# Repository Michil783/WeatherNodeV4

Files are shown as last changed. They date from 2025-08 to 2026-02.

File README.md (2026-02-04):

# WeatherNodeV4

WeatherNode is a small HW device based on ESP8266 to capture actual weather conditions as temperature, pressure and humidity.
The data is send via Wifi to a MQTT broker.
The back office SW is stored in

https://github.com/Michil783/ClimateHist

The applications could run on a Raspberry Pi together with the MQTT broker.

For displaying the data I created a web page using the Astro framework based on an other github project.
More details could be found here: 

https://github.com/Michil783/weather-forecast

## Hardware

The hardware schema is done in KiCAD and could be found in https://github.com/michil783/WeatherNodeV4/PCB

As weather sensor the Arduino Sensor Board BMP280 is used. For battery charging and programming a USB-C connector is onboard.

The PCB layout is also done with KiCAD and could also be found in this folder.

After taking the meassurements it goes to a deep sleep for 15 minutes and restart again for the next meassurement.

With a 18650 LiIon battery with ~3500mAh capacity you get a working time up to 8-10 weeks before you need to recharge the battery.

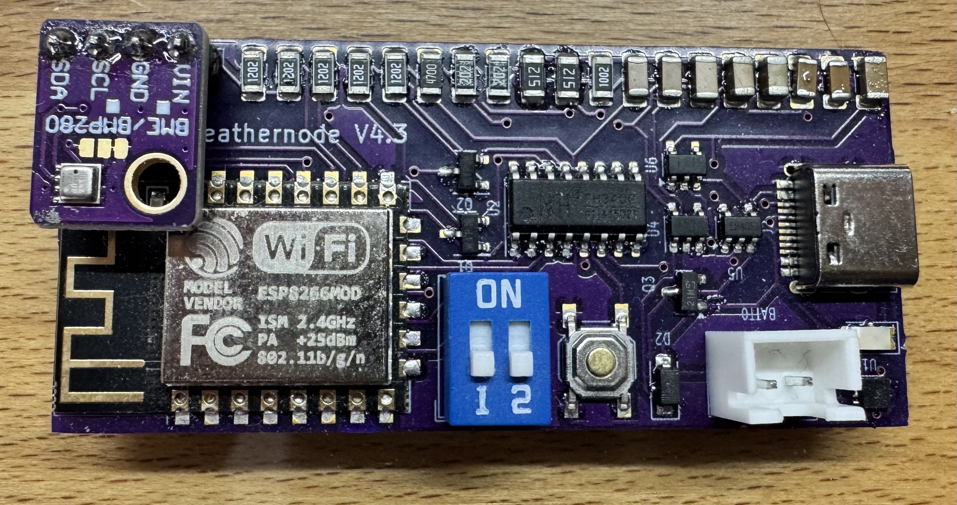
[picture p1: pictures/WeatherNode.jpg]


### Details of the hardware

#### USB controller
The USB controller is a CH340C

#### Charging controller
For charging and battery controlling the LTC4054 is used. It is configured to use about 500mA.

#### Battery watching
To get the current state of charge and the battery voltage a MAX17048 chip is used. It provides all necessary information.

#### Weather Sensor
To get all necessary climate values the BOSCH BMP280 circuit from Arduino is used.

#### CPU
As CPU the ESP8266 board is used. Wifi and I2C interfaces are already onboard.

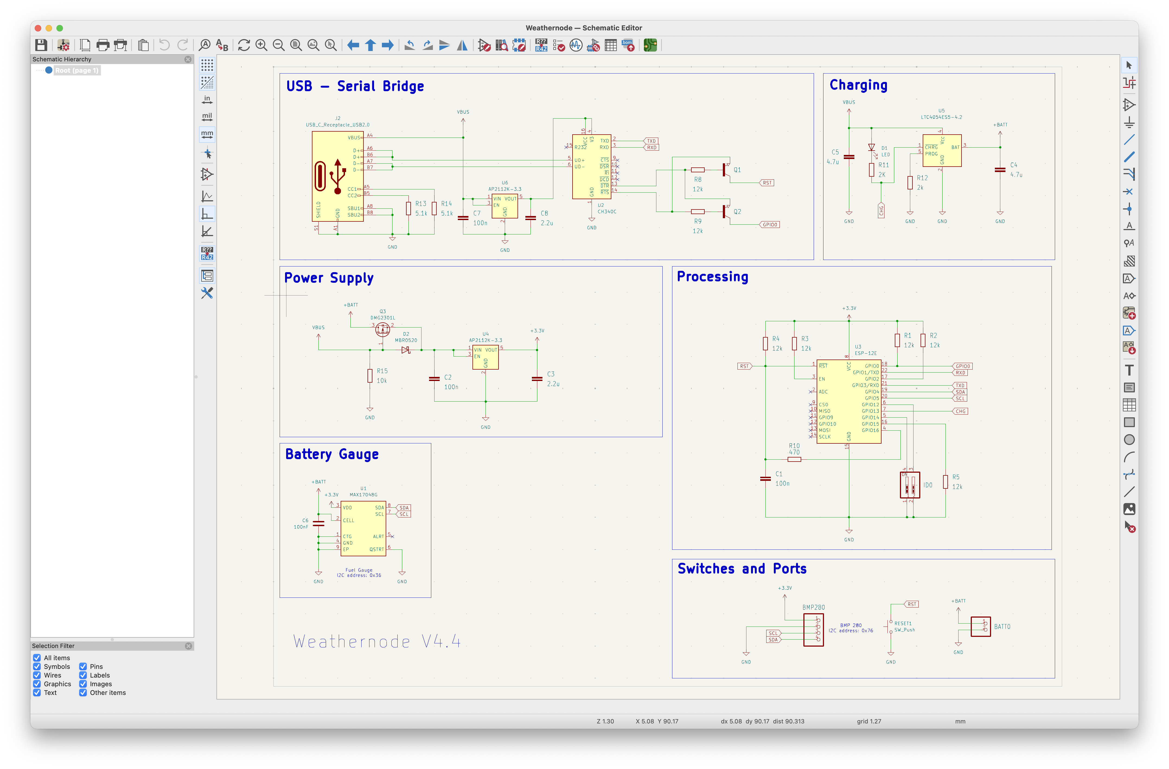
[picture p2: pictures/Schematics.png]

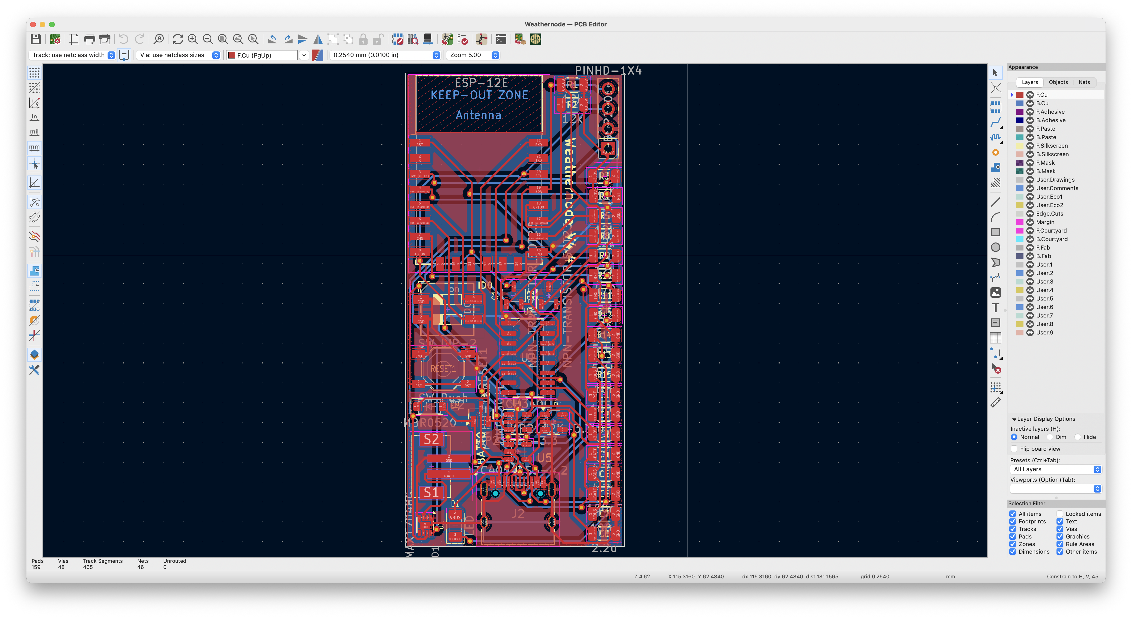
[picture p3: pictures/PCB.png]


## Software

The system provides a Wifi AP for the first installation. The AP name is "WeatherNode-Wifi-Manager" with an IP of 192.168.4.1. Accessing this IP from a browser you get the manager to configure the WeatherNode into your Wifi and with a proper ID.

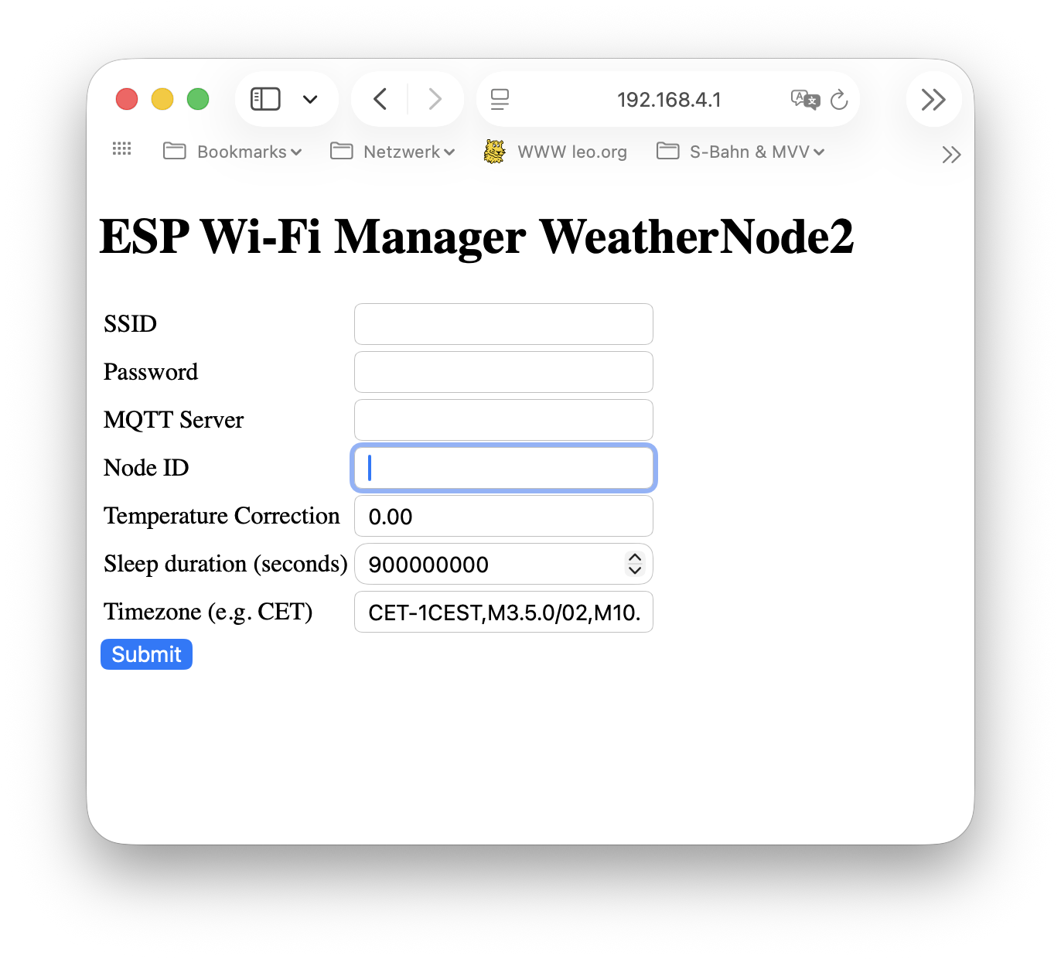
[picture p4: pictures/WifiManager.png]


When the WeatherNode is used the first time and no settings are stored via the programming the Wifi Manager starts automatically.

Via the DIP switches you could reset these settings on the board and restart the Wifi Manager.
With DIP switch 2 you do a reset and DIP switch 1 is starting the Wifi Manager without reseting the data.

When settings are available, the node starts up and is connectiong to the specified Wifi and to the MQTT broker. After this it initializes all components on the board and waits for 2 seconds before reading the data from the weather sensor. This is done to warmup the sensor to get a more precise measurement.

After taking the measurement it creates a JSON package and sends it to the MQTT broker.

If transmission of packet is successful it goes to a deep sleep for 15 minutes and the cycle begins again with a restart of the node.

## Housing

In the folder Box is a construction for a box for the WeatherNode including space for a 18650 battery.

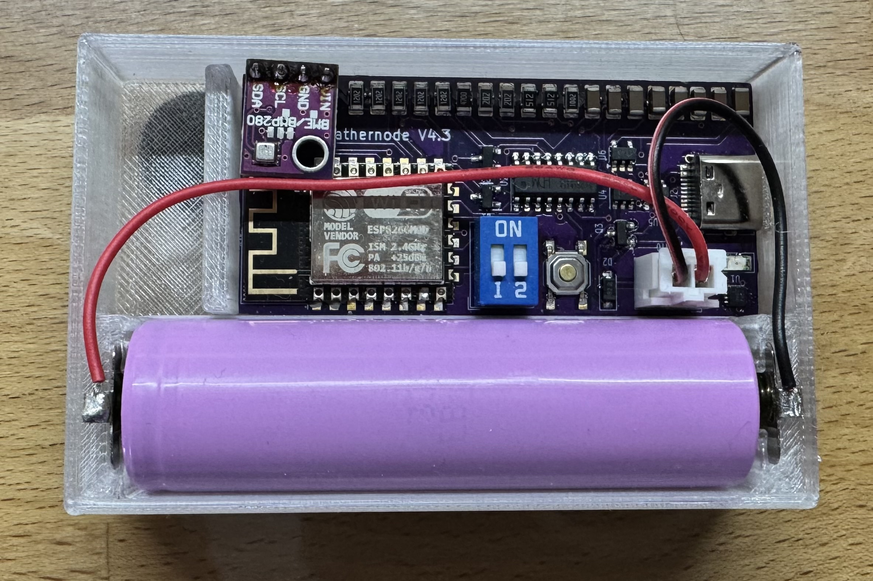
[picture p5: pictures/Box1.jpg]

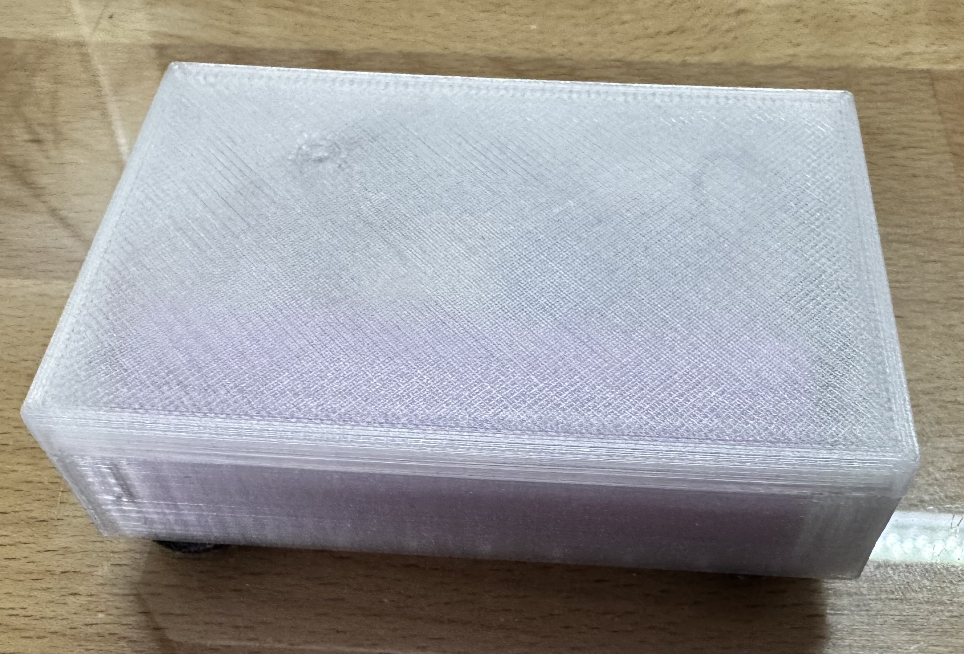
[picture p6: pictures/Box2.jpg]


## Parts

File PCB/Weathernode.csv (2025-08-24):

Id | Designator | Footprint | Quantity | Designation | Supplier and ref
1 | R12 | R_1206_3216Metric | 1 | 2k
2 | R13,R14 | R_1206_3216Metric | 2 | 5.1k
3 | R8,R2,R9,R3,R1,R4,R5 | R_1206_3216Metric | 7 | 12k
4 | U3 | ESP-12E | 1 | ESP-12E
5 | U5 | TSOT-23-5_HandSoldering | 1 | MCP73831
6 | U4,U6 | SOT-23-5 | 2 | AP2112K-3.3
7 | R11 | R_1206_3216Metric | 1 | 2K
8 | C7,C2,C1 | C_1206_3216Metric | 3 | 100n
9 | Q2,Q1 | SOT-23-3 | 2 | NPN-TRANSISTOR_SOT23
10 | D1 | LED_1206_3216Metric | 1 | LED
11 | Q3 | SOT-23 | 1 | DMG2301L
12 | C6 | C_1206_3216Metric | 1 | 100nF
13 | R15 | R_1206_3216Metric | 1 | 10k
14 | J2 | USB_C_Receptacle_HRO_TYPE-C-31-M-12 | 1 | USB_C_Receptacle_USB2.0
15 | C3,C8 | C_1206_3216Metric | 2 | 2.2u
16 | U2 | SOIC-16_3.9x9.9mm_P1.27mm | 1 | CH340C
17 | U1 | TDFN-8-1EP_2x2mm_P0.5mm_EP0.8x1.2mm | 1 | MAX17048G
18 | ID0 | SW_DIP_SPSTx02_Slide_6.7x6.64mm_W6.73mm_P2.54mm_LowProfile_JPin | 1 | SW_DIP-2
19 | BMP280 | PinHeader_1x04_P2.54mm_Vertical | 1 | PINHD-1X4
20 | C5,C4 | C_1206_3216Metric | 2 | 4.7u
21 | D2 | D_SOD-123 | 1 | MBR0520
22 | RESET1 | SW_SPST_TL3342 | 1 | SW_Push
23 | R10 | R_1206_3216Metric | 1 | 470
24 | BATT0 | JST_PH_B2B-PH-SM4-TB_1x02-1MP_P2.00mm_Vertical | 1 | PINHD-1X2

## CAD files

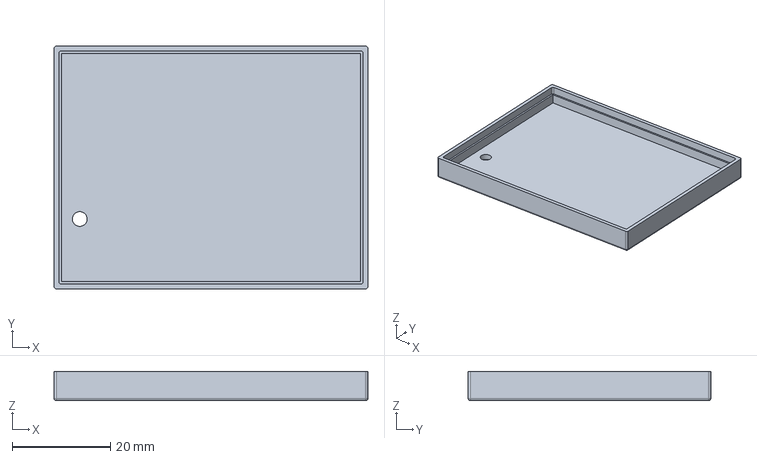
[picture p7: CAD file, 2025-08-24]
Box/WeathernodeV4_Oberteil.FCStd
64.0 x 49.5 x 6.00 mm

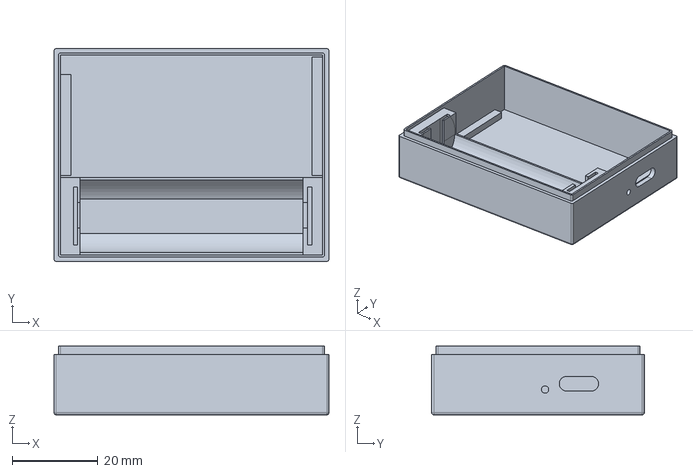
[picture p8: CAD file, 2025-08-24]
Box/WeathernodeV4_Unterteil.FCStd
64.0 x 49.5 x 16.0 mm

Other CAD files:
Box/WeathernodeV4_Oberteil.stl
Box/WeathernodeV4_Unterteil.stl

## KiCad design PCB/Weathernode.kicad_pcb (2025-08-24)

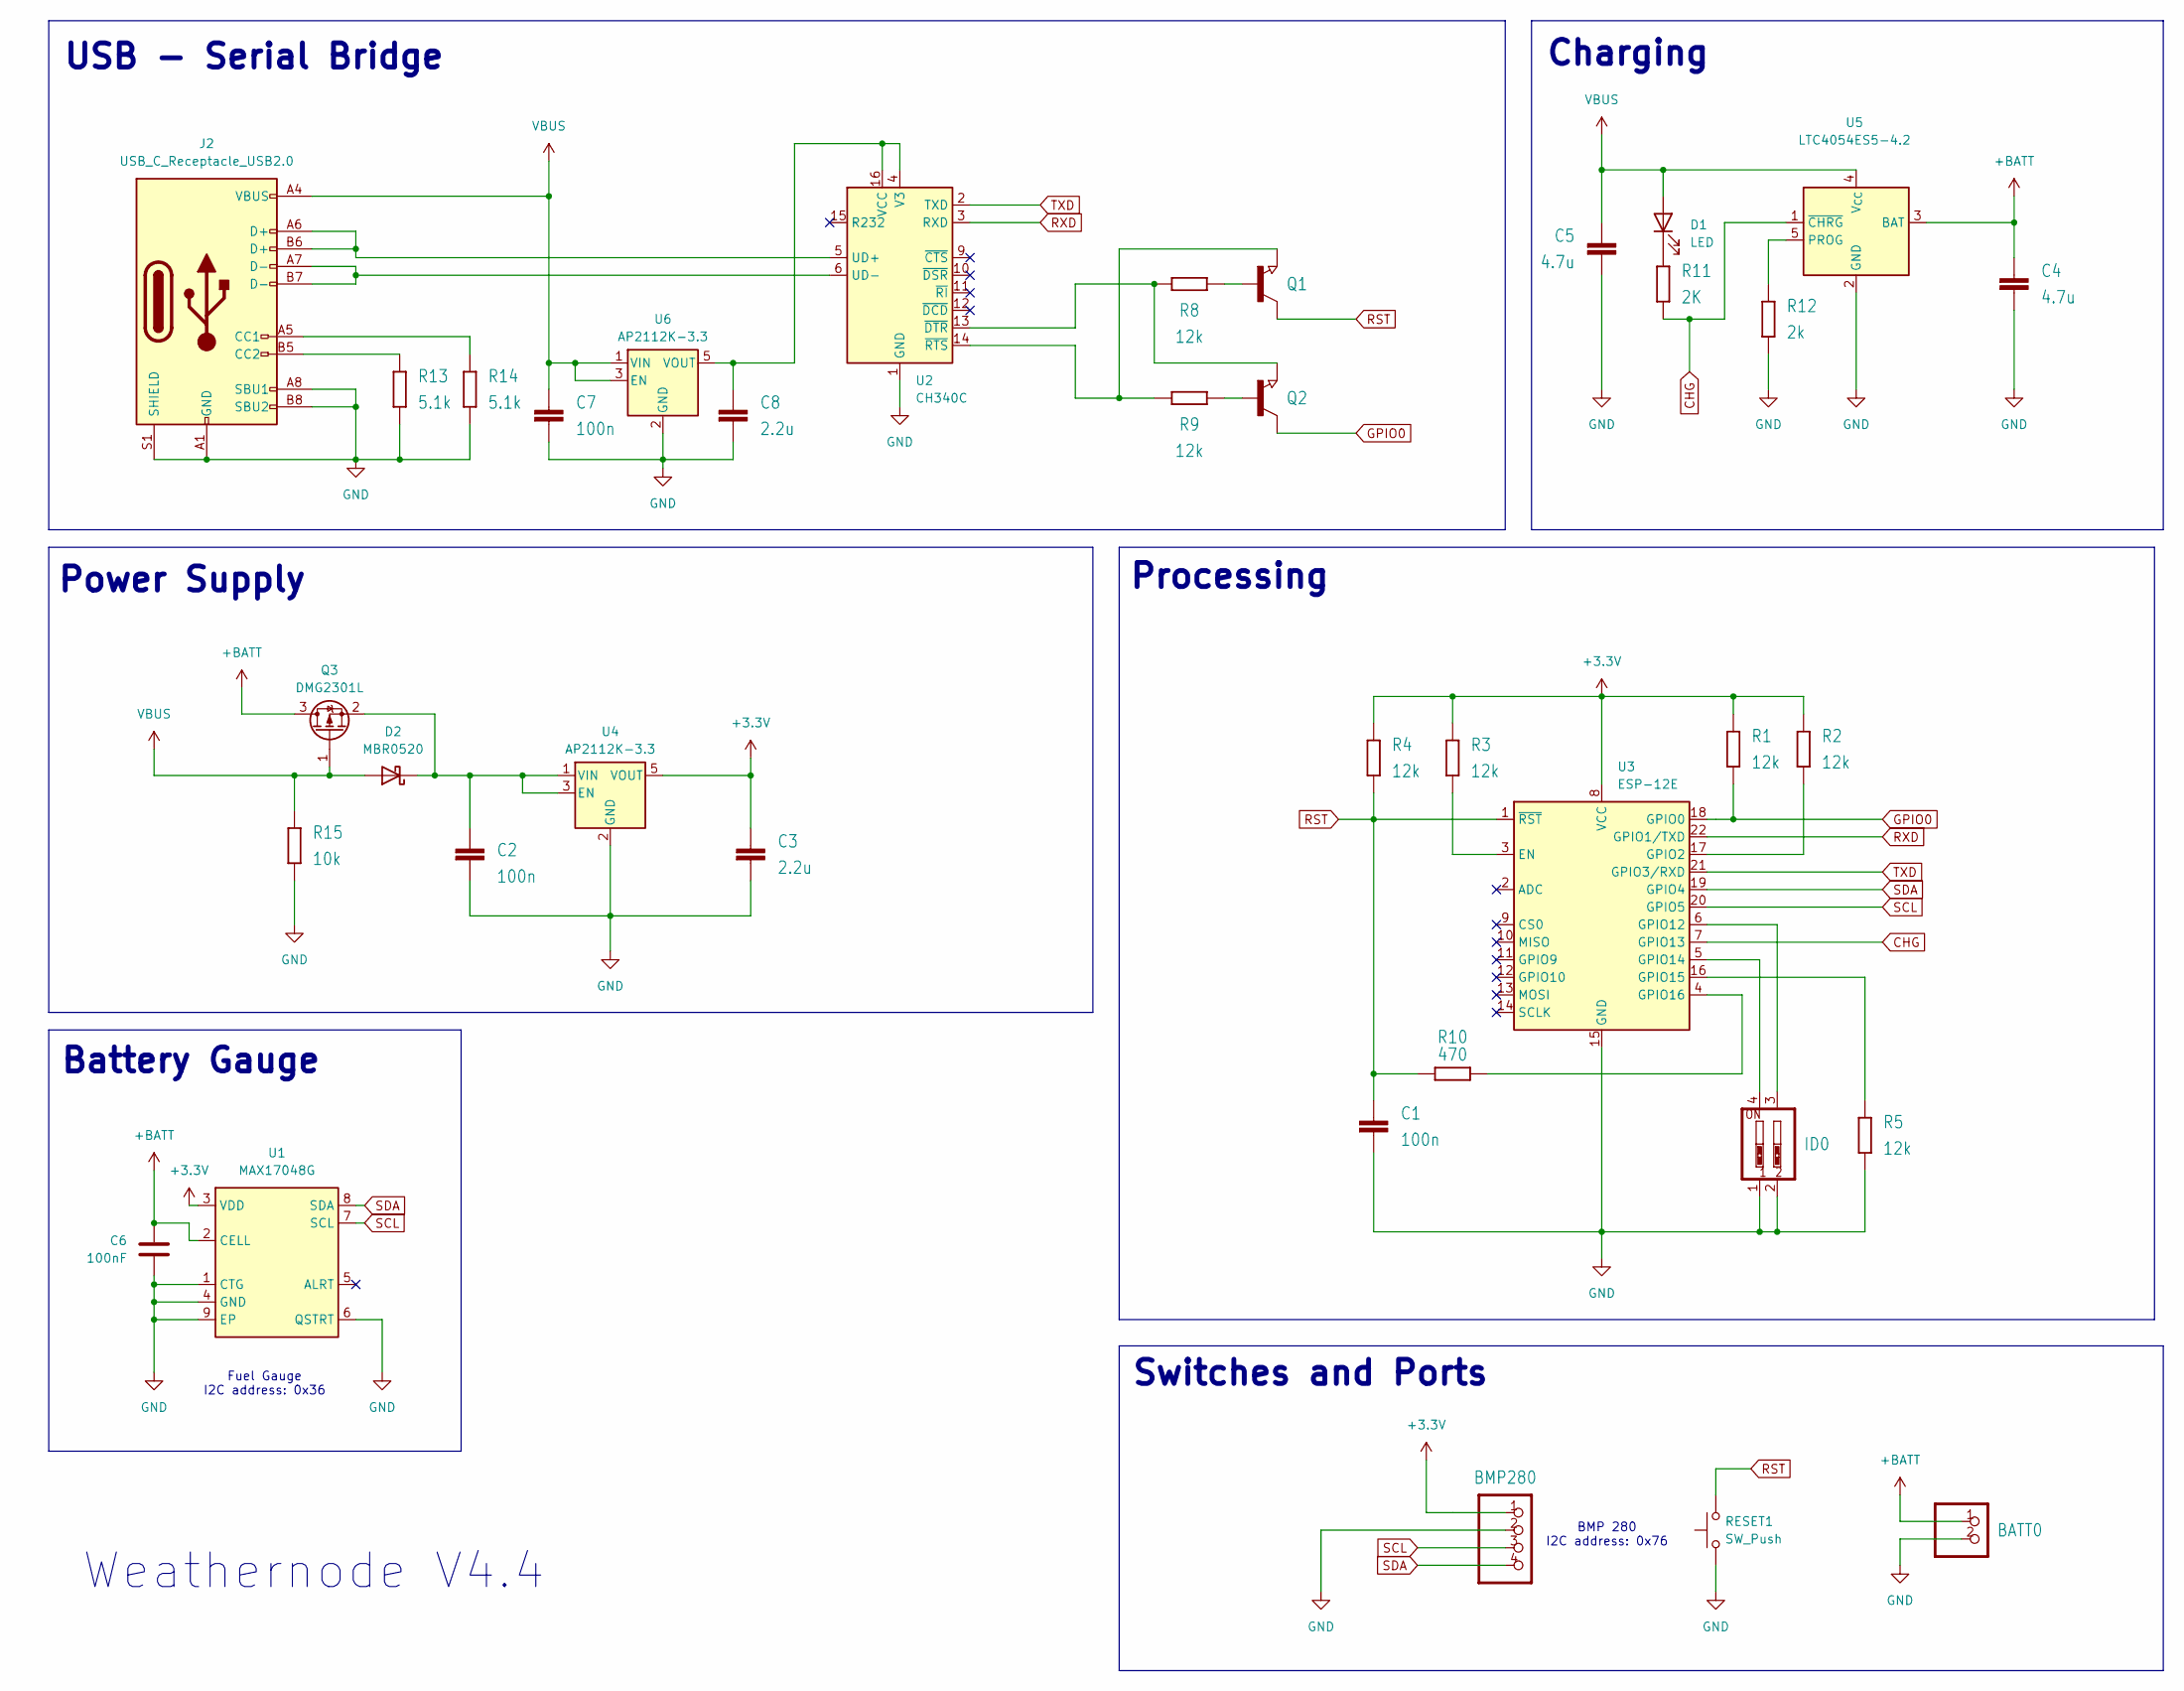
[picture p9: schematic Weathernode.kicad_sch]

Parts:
BATT0: PINHD-1X2; JST_B2B-PH-SM4-TB
BMP280: PINHD-1X4; PinHeader_1x04_P2.54mm_Vertical
C1, C2, C7: 100n; C_1206_3216Metric
C3, C8: 2.2u; C_1206_3216Metric
C4, C5: 4.7u; C_1206_3216Metric
C6: 100nF; C_1206_3216Metric; LCSC C1591
D1: LED; LED_1206_3216Metric
D2: MBR0520; D_SOD-123
ID0: SW_DIP-2; SW_DIP_SPSTx02_Slide_6.7x6.64mm_W6.73mm_P2.54mm_LowProfile_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
J2: USB_C_Receptacle_USB2.0; USB_C_Receptacle_HRO_TYPE-C-31-M-12
Q1, Q2: NPN-TRANSISTOR_SOT23; SOT-23-3
Q3: DMG2301L; SOT-23
R1, R2, R3, R4, R5, R8, R9: 12k; R_1206_3216Metric
R10: 470; R_1206_3216Metric
R11: 2K; R_1206_3216Metric
R12: 2k; R_1206_3216Metric
R13, R14: 5.1k; R_1206_3216Metric
R15: 10k; R_1206_3216Metric
RESET1: SW_Push; SW_SPST_TL3342
U1: MAX17048G; TDFN-8-1EP_2x2mm_P0.5mm_EP0.8x1.2mm; LCSC C2682616
U2: CH340C; SOIC-16_3.9x9.9mm_P1.27mm
U3: ESP-12E
U4, U6: AP2112K-3.3; SOT-23-5
U5: LTC4054ES5-4.2; TSOT-23-5

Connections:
CHG: R11.1, U3.7 (GPIO13), U5.1 (~CHRG)
GND: BATT0.2, BMP280.2, C1.2, C2.2, C3.2, C4.2, C5.2, C6.2, C7.2, C8.2, ID0.1, ID0.2, J2.A1 (GND), J2.A8 (SBU1), J2.A12 (GND), J2.B1 (GND), J2.B8 (SBU2), J2.B12 (GND), J2.S1 (SHIELD), R5.2, R12.1, R13.2, R14.2, R15.2, RESET1.1, U1.1 (CTG), U1.4 (GND), U1.6 (QSTRT), U1.9 (EP), U2.1 (GND), U3.15 (GND), U4.2 (GND), U5.2 (GND), U6.2 (GND)
GPIO0: Q2.3 (C), R1.1, U3.18 (GPIO0)
unnamed: D1.1 (K), R11.2
unnamed: C2.1, D2.1 (K), Q3.2 (S), U4.1 (VIN), U4.3 (EN)
unnamed: J2.A5 (CC1), R14.1
unnamed: J2.B5 (CC2), R13.1
unnamed: Q1.1 (B), R8.1
unnamed: Q1.2 (E), R9.2, U2.14 (~RTS)
unnamed: Q2.1 (B), R9.1
unnamed: Q2.2 (E), R8.2, U2.13 (~DTR)
unnamed: J2.A6 (D+), J2.B6 (D+), U2.5 (UD+)
unnamed: J2.A7 (D-), J2.B7 (D-), U2.6 (UD-)
unnamed: C8.1, U2.4 (V3), U2.16 (VCC), U6.5 (VOUT)
unnamed: R3.2, U3.3 (EN)
unnamed: R2.1, U3.17 (GPIO2)
unnamed: ID0.3, U3.6 (GPIO12)
unnamed: ID0.4, U3.5 (GPIO14)
unnamed: R5.1, U3.16 (GPIO15)
unnamed: R10.2, U3.4 (GPIO16)
unnamed: R12.2, U5.5 (PROG)
RST: C1.1, Q1.3 (C), R4.2, R10.1, RESET1.2, U3.1 (~RST)
RXD: U2.3 (RXD), U3.22 (GPIO1/TXD)
SCL: BMP280.3, U1.7 (SCL), U3.20 (GPIO5)
SDA: BMP280.4, U1.8 (SDA), U3.19 (GPIO4)
TXD: U2.2 (TXD), U3.21 (GPIO3/RXD)
VBUS: C5.1, C7.1, D1.2 (A), D2.2 (A), J2.A4 (VBUS), J2.A9 (VBUS), J2.B4 (VBUS), J2.B9 (VBUS), Q3.1 (G), R15.1, U5.4 (V_{CC}), U6.1 (VIN), U6.3 (EN)

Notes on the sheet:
Weathernode V4.4
Power Supply
BMP 280 I2C address: 0x76
Switches and Ports
Fuel Gauge I2C address: 0x36
Charging
Processing
Battery Gauge
USB - Serial Bridge

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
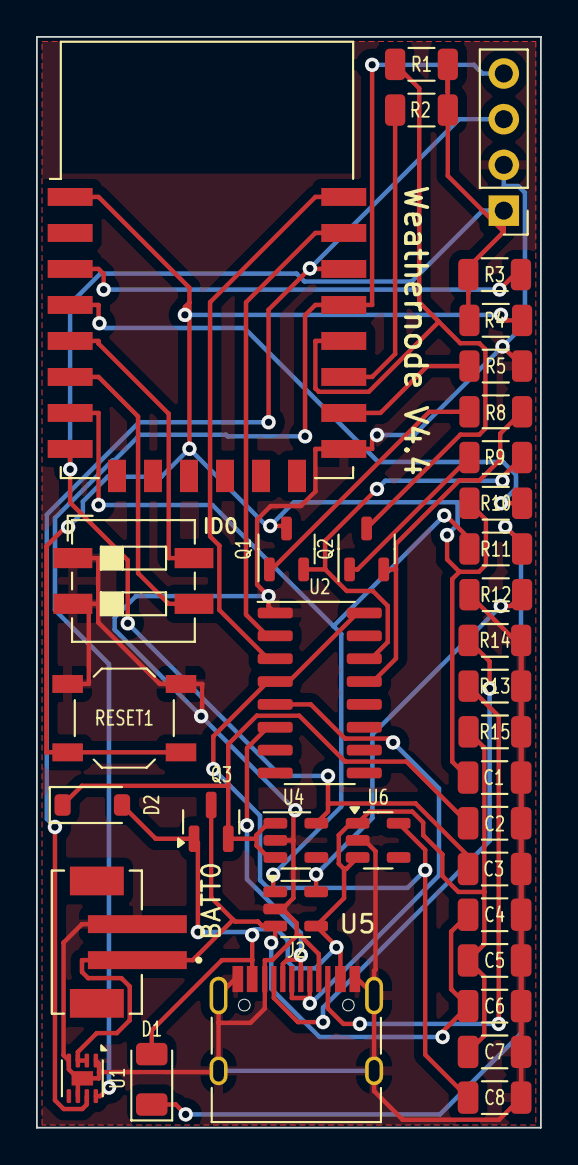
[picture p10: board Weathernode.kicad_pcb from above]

Board: 2 copper layers, 28.0 x 60.6 mm, 37 parts (0 on the bottom side), 29 nets.

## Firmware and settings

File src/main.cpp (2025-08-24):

#include <Arduino.h>
#include <DNSServer.h>
const byte DNS_PORT = 53;
DNSServer dnsServer;

//#define DEBUG
#define DO_DEEPSLEEP
#define DO_PUBLISH
#ifdef DO_PUBLISH
  #ifdef DEBUG
    #define DEEPSLEEPDURATION 10*1000*1000 // 10 seconds
  #else
    #define DEEPSLEEPDURATION 15*60*1000*1000 // 15 minutes
  #endif
#else
  #define DEEPSLEEPDURATION 5*1000*1000 // 5 seconds
#endif

bool do_publish = true;
bool bmp_init = false;
bool max_init = false;

#ifdef ESP32
  #include <ESPAsyncWebServer.h>
  #define MANAGER_PIN 23
  #define PUBLISH_PIN   19
  #define CHARGE_PIN  13
#elif defined( ESP8266 )
  // Including the ESP8266 WiFi library
  #include <ESP8266WiFi.h>
  #include <ESPAsyncWebServer.h>
  extern "C" {
    #include "gpio.h"
  }
  extern "C" {
    #include "user_interface.h"
  }
  #define MANAGER_PIN 14
  #define PUBLISH_PIN   12
  #define CHARGE_PIN  13
  
#endif

#include "FS.h"
#include <LittleFS.h>

#include <ESPAsyncHTTPUpdateServer.h>

ESPAsyncHTTPUpdateServer updateServer;
AsyncWebServer server(80);

#include <Wire.h>
#include <Adafruit_BME280.h>
Adafruit_BME280 bmp;

#include <SparkFun_MAX1704x_Fuel_Gauge_Arduino_Library.h>
SFE_MAX1704X fuelGauge(MAX1704X_MAX17048);

#include <ArduinoJson.h>
#include <PubSubClient.h>
#include <time.h>

time_t now;

// Define NTP Client to get time
const char* ntpServer = "ntp1.t-online.de"; //"pool.ntp.org";
const long  gmtOffset_sec = 3600;
const int   daylightOffset_sec = 3600;

char WEATHERNODE[20];
int nodeNumber = 0;

// File paths to save input values permanently
const char* ssidPath  = "/ssid.txt";
const char* passPath  = "/pass.txt";
const char* mqttPath  = "/mqtt.txt";
const char* idPath    = "/id.txt";
const char* sleepPath = "/sleep.txt";
const char* tempPath  = "/temp.txt";
const char* timePath  = "/time.txt";

// Replace with your network details
//Variables to save values from HTML form
String ssid = "";
String pass;
String ip;
String mqtt_server = "hap-nodejs";
const char* mqtt_topic = WEATHERNODE;
int nodeId = 0;
int sleepDuration = DEEPSLEEPDURATION;
String myTimeZone = "CET";
float tempCorrection = 0.0;

long lastMsg = 0;
int value = 0;
char json[600];

WiFiClient espClient;
PubSubClient client(espClient);

// Temporary variables
static char celsiusTemp[7];
static char heatIndexTemp[7];
static char humidityTemp[7];
static char pressureTemp[7];
static char dewPTemp[7];
static char voltageTemp[7];

float dst,bt,bp,ba;
char dstmp[20],btmp[20],bprs[20],balt[20];
int clientCounter;
int publishCounter;

void i2cScanner() {
  byte error, address;
  int nDevices;
  Serial.println("Scanning...");
  nDevices = 0;
  for(address = 1; address < 127; address++ ) {
    Serial.print(".");
    Wire.beginTransmission(address);
    error = Wire.endTransmission();
    if (error == 0) {
      nDevices++;
      Serial.printf("\ndevice found at 0x%02x\n", address);
    }
    else if (error==4) {
      Serial.printf("\nUnknown error at address 0x%02x\n", address);
    }
  }
  if (nDevices == 0) {
    Serial.println("\nNo I2C devices found\n");
  }
  else {
    Serial.println("\ndone\n");
  }
}

bool getWiFiManager() {
  if( digitalRead(MANAGER_PIN) == 0 ) {
    return true;
  }
  return false;
}

bool getPublish() {
  if( digitalRead(PUBLISH_PIN) == 0 ) {
    return true;
  }
  return false;
}

bool isCharging() {
  Serial.printf("isCharging(): CHARGE_PIN: %d MAX Changerate: %f\n", digitalRead(CHARGE_PIN), fuelGauge.getChangeRate());
  if( digitalRead(CHARGE_PIN) == 0 )
    return true;
  return false;
}

float convertCtoF(float c) {
  return c * 1.8 + 32;
}

float convertFtoC(float f) {
  return (f - 32) * 0.55555;
}

float computeHeatIndex(float temperature, float percentHumidity, bool isFahrenheit) {
  // Using both Rothfusz and Steadman's equations
  // http://www.wpc.ncep.noaa.gov/html/heatindex_equation.shtml
  float hi;

  if (!isFahrenheit)
    temperature = convertCtoF(temperature);

  hi = 0.5 * (temperature + 61.0 + ((temperature - 68.0) * 1.2) + (percentHumidity * 0.094));

  if (hi > 79) {
    hi = -42.379 +
             2.04901523 * temperature +
            10.14333127 * percentHumidity +
            -0.22475541 * temperature*percentHumidity +
            -0.00683783 * pow(temperature, 2) +
            -0.05481717 * pow(percentHumidity, 2) +
             0.00122874 * pow(temperature, 2) * percentHumidity +
             0.00085282 * temperature*pow(percentHumidity, 2) +
            -0.00000199 * pow(temperature, 2) * pow(percentHumidity, 2);

    if((percentHumidity < 13) && (temperature >= 80.0) && (temperature <= 112.0))
      hi -= ((13.0 - percentHumidity) * 0.25) * sqrt((17.0 - abs(temperature - 95.0)) * 0.05882);

    else if((percentHumidity > 85.0) && (temperature >= 80.0) && (temperature <= 87.0))
      hi += ((percentHumidity - 85.0) * 0.1) * ((87.0 - temperature) * 0.2);
  }

  return isFahrenheit ? hi : convertFtoC(hi);
}

float calcDewpoint(float humi, float temp) {
  //Serial.println("calcDewPoint()");

  float k;
  k = log(humi/100) + (17.62 * temp) / (243.12 + temp);
  return 243.12 * k / (17.62 - k);
}

void reconnectMqtt() {
  // Loop until we're reconnected
  Serial.println("reconnectMqtt()");
  while (!client.connected() && clientCounter < 5) {
    Serial.printf("Attempting MQTT connection to %s\n", mqtt_server.c_str());
    // Attempt to connect
    if (client.connect("ESPClient")) {
      Serial.println("connected");
    } else {
      Serial.printf("failed, rc=%d\n", client.state());
      Serial.println(" try again in 5 seconds");
      // Wait 3 seconds before retrying
      delay(5000);
      clientCounter++;
    }
  }
  if( !client.connected() && clientCounter == 5 ) {
    Serial.println("could not connect to MQTT server, restart ESP");
    ESP.restart();
  }
}

float mapfloat(float x, float in_min, float in_max, float out_min, float out_max)
{
  return (x - in_min) * (out_max - out_min) / (in_max - in_min) + out_min;
}

float getVoltage() {
  Serial.println("getVoltage()");
  float busvoltage;
  if( max_init )
    busvoltage = fuelGauge.getVoltage();
  else
    busvoltage = 0.0;
  Serial.printf("busvoltage: %1.2f\n", busvoltage);
  do_publish = true;
  return busvoltage;
}

float getSOC() {
  return fuelGauge.getSOC();
}

float getChangeRate() {
  return fuelGauge.getChangeRate();
}

bool getSensorData() {
  Serial.println("getSensorData()");
  if( bmp_init ) {
    float vin = getVoltage();
    snprintf (voltageTemp, 6, "%1.2f", vin);
    Serial.printf("Vin: %f\n", vin);

    Serial.println("before takeForcedMeasurement");
    Serial.printf("bmp.takeForcedMeasurement() = %s\n", bmp.takeForcedMeasurement() ? "TRUE" : "FALSE");
    float bp =  bmp.readPressure()/100;
    Serial.printf("readPressure: %fhPa\n", bp);
    float h =   bmp.readHumidity();
    Serial.printf("readHumidity: %f%%\n", h);
    float t =   bmp.readTemperature(); 
    Serial.printf("readTemperature: %fC\n", t);
    t = t + tempCorrection;
    Serial.printf("readTemperature after tempCorrection (%f): %fC\n", tempCorrection, t);
    float hic = computeHeatIndex(t, h, false);       
    Serial.printf("heatIndex: %f\n", hic);
    Serial.printf("dew point: %fC\n", calcDewpoint(h, t));
    snprintf (celsiusTemp, 6, "%2.1f", t);             
    snprintf (heatIndexTemp, 6, "%2.1f", hic);
    snprintf (humidityTemp, 6, "%3.0f", h);
    snprintf (pressureTemp, 6, "%4.0f", bp);
    snprintf (dewPTemp, 6, "%2.1f", calcDewpoint(h, t));
  }
  return true;
}

bool getJSON() {
  Serial.println("getJSON()");
  StaticJsonDocument<500> doc;

  bool status = getSensorData();

  Serial.print("now: ");
  time(&now);
  Serial.println( now );
  
  Serial.println("create JSON data");

  Serial.printf("clientCounter: %d\n", clientCounter);
  Serial.printf("publishCounter: %d\n", publishCounter);

  doc["time"] = now;
  doc["temperature"] = celsiusTemp;
  doc["heatindex"] = heatIndexTemp;
  doc["dewpoint"] = dewPTemp;
  doc["humidity"] = humidityTemp;
  doc["pressure"] = pressureTemp;
  doc["voltage"] = voltageTemp;
  doc["clientcounter"] = clientCounter;
  doc["publishcounter"] = publishCounter;
  doc["charging"] = (isCharging()?"true":"false");
  doc["soc"] = String(getSOC());
  doc["chgrate"] = String(getChangeRate());
  doc["chgpin"] = String(digitalRead(CHARGE_PIN));
  serializeJson(doc, json);
  Serial.printf("doc size: %d json size: %d\n", sizeof(doc), sizeof(json));

  Serial.printf( "getJSON() status: %d\n", status );
  return status;
}

// Delete file from FS
bool deleteFile(const char * path) {
  Serial.printf("deleting file: %s\n", path);
  if( LittleFS.exists(path) )
    return LittleFS.remove(path);
  else
    Serial.println("file does not exist");
  return false;
}

// Read File from FS
String readFile(const char * path){
  Serial.printf("Reading file: %s\r\n", path);

  File file = LittleFS.open(path, "r");
  if(!file || file.isDirectory()){
    Serial.println("- failed to open file for reading");
    return String();
  }

  String fileContent;
  while(file.available()){
    fileContent = file.readString(); // readStringUntil('\n');
    break;     
  }
  file.close();
  return fileContent;
}

// Write file to LittleFS
void writeFile(const char * path, const char * message){
  Serial.printf("Writing file: %s\r\n", path);

  File file = LittleFS.open(path, "w");
  if(!file){
    Serial.println("- failed to open file for writing");
    return;
  }
  if(file.print(message)){
    //Serial.println("- file written");
  } else {
    Serial.println("- frite failed");
  }
  file.close();
}

// Search for parameter in HTTP POST request
const char* PARAM_INPUT_1 = "ssid";
const char* PARAM_INPUT_2 = "pass";
const char* PARAM_INPUT_3 = "mqttserver";
const char* PARAM_INPUT_4 = "nodeid";
const char* PARAM_INPUT_5 = "adccorrection";
const char* PARAM_INPUT_6 = "sleepduration";
const char* PARAM_INPUT_7 = "tempcorrection";
const char* PARAM_INPUT_8 = "timezone";

String webServerProcessor(const String& var) {
  Serial.printf("webServerProcessor(\"%s\")\n", var.c_str());
  if (var == "NODE_ID"){
    //int nodeNumber = getNodeId();
    Serial.printf("NODE_ID: %d\n", nodeId);
    return String(nodeId);
  }
  if (var == "MQTTSERVER"){
    Serial.printf("MQTTSERVER: %s\n", mqtt_server.c_str());
    return mqtt_server;
  }
  if (var == "SSID"){
    Serial.printf("SSID: %s\n", ssid.c_str());
    return ssid.c_str();
  }
  if (var == "PASS"){
    Serial.printf("PASS: %s\n", pass.c_str());
    return pass.c_str();
  }
  if (var == "NODEID"){
    Serial.printf("NODEID: %d\n", nodeId);
    return String(nodeId);
  }
  if (var == "TEMPCORRECTION"){
    Serial.printf("TEMPCORRECTION: %f\n", tempCorrection);
    return String(tempCorrection);
  }
  if (var == "SLEEPDURATION"){
    Serial.printf("SLEEPDURATION: %d\n", sleepDuration);
    return String(sleepDuration);
  }
  if (var == "TIMEZONE"){
    Serial.printf("TIMEZONE: %s\n", myTimeZone.c_str());
    return String(myTimeZone);
  }
  return String();
}

void startWiFiManager() {
  // Connect to Wi-Fi network with SSID and password
  Serial.println("Setting AP (Access Point)");
  // NULL sets an open Access Point
  WiFi.softAP("WeatherNode-WiFi-Manager", NULL);
  Serial.printf("connect to: %s\n", "WeatherNode-WiFi-Manager");

  digitalWrite(LED_BUILTIN, LOW);

  IPAddress IP = WiFi.softAPIP();
  WiFi.setHostname("WeatherNode");
  Serial.print("AP IP address: ");
  Serial.println(IP); 

  dnsServer.start(DNS_PORT, "*", IP);

  // Web Server Root URL
  server.on("/", HTTP_GET, [](AsyncWebServerRequest *request){
    Serial.println("server.on(\"/\", HTTP_GET, ...)");
    request->send(LittleFS, "/wifimanager.html", "text/html", false, webServerProcessor);
  });

  server.serveStatic("/", LittleFS, "/wifimanager.html");

  server.on("/", HTTP_POST, [](AsyncWebServerRequest *request) {
    Serial.println("server.on(\"/\", HTTP_POST, ...)");
    int params = request->params();
    for(int i=0;i<params;i++){
      AsyncWebParameter* p = request->getParam(i);
      if(p->isPost()){
        // HTTP POST ssid value
        if (p->name() == PARAM_INPUT_1) {
          ssid = p->value().c_str();
          Serial.printf("SSID set to: %s\n", ssid.c_str());
          // Write file to save value
          writeFile(ssidPath, ssid.c_str());
        }
        // HTTP POST pass value
        if (p->name() == PARAM_INPUT_2) {
          pass = p->value().c_str();
          Serial.printf("Password set to: %s\n", pass.c_str());
          // Write file to save value
          writeFile(passPath, pass.c_str());
        }
        // HTTP POST mqttserver value
        if (p->name() == PARAM_INPUT_3) {
          mqtt_server = p->value().c_str();
          Serial.printf("MQTT Server set to: %s\n", mqtt_server.c_str());
          // Write file to save value
          writeFile(mqttPath, mqtt_server.c_str());
        }
        // HTTP POST idBase value
        if (p->name() == PARAM_INPUT_4) {
          nodeId = p->value().toInt();
          Serial.printf("nodeId set to: %d\n", nodeId);
          // Write file to save value
          writeFile(idPath, String(nodeId).c_str());
        }
        // HTTP POST sleepduration value
        if (p->name() == PARAM_INPUT_6) {
          sleepDuration = p->value().toInt();
          Serial.printf("sleepDuration set to: %d\n", sleepDuration);
          // Write file to save value
          writeFile(sleepPath, String(sleepDuration).c_str());
        }
        // HTTP POST sleepduration value
        if (p->name() == PARAM_INPUT_7) {
          tempCorrection = p->value().toFloat();
          Serial.printf("tempCorrection set to: %f\n", tempCorrection);
          // Write file to save value
          writeFile(tempPath, String(tempCorrection).c_str());
        }
        // HTTP POST timezone value
        if (p->name() == PARAM_INPUT_8) {
          myTimeZone = p->value().c_str();
          Serial.printf("timezone set to: %s\n", myTimeZone.c_str());
          // Write file to save value
          writeFile(timePath, myTimeZone.c_str());
        }
      }
    }
    request->send(200, "text/plain", "Done. ESP will restart");
    delay(3000);
    ESP.restart();
  });
  //server.begin();
  Serial.println("start WiFiManager finished");
}

bool initWiFi() {
    if(ssid == "" || pass == ""){
        Serial.println("Undefined SSID or password");
        return false;
    }
    if( getWiFiManager() ){
        Serial.println("start WifiManager via PIN");
        return false;
    }
    // if( getPublish() ){
    //     Serial.println("start WifiManager via Reset PIN");
    //     deleteFile(ssidPath);
    //     deleteFile(passPath);
    //     writeFile(mqttPath, "hap-nodejs");
    //     writeFile(idPath, "0");
    //     writeFile(adcPath, "0.0");
    //     writeFile(sleepPath, "900000000");
    //     ESP.restart();
    //     return false;
    // }
    return true;
}
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
void loop() {
  dnsServer.processNextRequest();
  if( WiFi.getMode() ==  WIFI_STA ) {
    time(&now);
    
    //if( now > lastPublish + (sleepDuration/1000/1000) ) {
      if (!client.connected()) {
          reconnectMqtt();
      }
      client.loop();

      tm tm;
      localtime_r(&now, &tm);
      Serial.printf("\nTimestamp: %lld\n", now );
      Serial.printf("Date: %02d.%02d.%04d %02d:%02d:%02d (DST=%d)\n", tm.tm_mday, tm.tm_mon+1, tm.tm_year+1900, tm.tm_hour, tm.tm_min, tm.tm_sec, tm.tm_isdst );

      bool status = getJSON();
      Serial.printf("Publish to topic: %s\n", mqtt_topic);
      Serial.printf("Publish message: %s\n", json);
      Serial.println(sizeof(json));
      if( status == true ) {
        if( do_publish && !getPublish() ) {
          if ( client.publish(mqtt_topic, json, false) == true ) {
            Serial.println("succcess");
            delay(1000);
            client.disconnect();
            // store last publish time
            //time(&lastPublish);
            #ifdef DO_DEEPSLEEP    
              Serial.printf("go to deep sleep for %ds\n", sleepDuration/(1000*1000));
              #ifdef ESP32
                esp_sleep_enable_timer_wakeup(sleepDuration);
                esp_deep_sleep_start();
              #else
                ESP.deepSleep(sleepDuration, WAKE_RF_DEFAULT);
                //Serial.printf("no not deep sleep but do not request new data for the next %d seconds\n", sleepDuration/1000/1000/60);
              #endif
            #else
              Serial.println("delay for 1000ms");
              delay(1000);
            #endif
          } else {
            Serial.println("publish failed");
            delay(1000);
            publishCounter++;
            ESP.restart();
          }
          //Serial.print("do publish to: ");
          //Serial.println(WEATHERNODE);
          //Serial.println(json);
          //client.disconnect();
        }
        else {
          if( !getPublish() )
            Serial.println("publish not done due to failed HW init");
          else
            Serial.println("publish not done due to DO_PUBLISH SWITCH");
          Serial.printf("go to deep sleep for rebooting %ds\n", sleepDuration/(1000*1000)); 
          #ifdef ESP32
            esp_sleep_enable_timer_wakeup(sleepDuration);
            esp_sleep_pd_config(ESP_PD_DOMAIN_MAX, ESP_PD_OPTION_OFF);
            esp_sleep_pd_config(ESP_PD_DOMAIN_RTC_PERIPH, ESP_PD_OPTION_OFF);
            esp_sleep_pd_config(ESP_PD_DOMAIN_RTC_SLOW_MEM, ESP_PD_OPTION_OFF);
            esp_sleep_pd_config(ESP_PD_DOMAIN_RTC_FAST_MEM, ESP_PD_OPTION_OFF);
            esp_deep_sleep_start();
          #else
            #ifdef MAX1704x
              if( max_init )
                fuelGauge.sleep();
              else
                Serial.println("MAX1704x init failed, no sleep for it");
            #endif
            ESP.deepSleep(sleepDuration, WAKE_RF_DEFAULT);
            //Serial.printf("no not deep sleep but do not request new data for the next %d seconds\n", sleepDuration/1000/1000/60);
          #endif
        }
      } else {
          Serial.println("status != true");
          delay(1000);
      }
    // } else if( now > lastPublish ) {
    //   tm tm, tml;
    //   localtime_r(&now, &tm);
    //   localtime_r(&lastPublish, &tml);
    //   Serial.printf("Date: %02d.%02d.%04d %02d:%02d:%02d (DST=%d) last publish %02d.%02d.%04d %02d:%02d:%02d (DST=%d) wait for %ds\r", 
    //     tm.tm_mday, tm.tm_mon+1, tm.tm_year+1900, tm.tm_hour, tm.tm_min, tm.tm_sec, tm.tm_isdst,
    //     tml.tm_mday, tml.tm_mon+1, tml.tm_year+1900, tml.tm_hour, tml.tm_min, tml.tm_sec, tml.tm_isdst,(sleepDuration/1000/1000) );
    // }
  }
  else {
    #ifdef DEBUG
      #ifndef MAX1704x
        int rawVoltage = publishCounter = analogRead(ADC_PIN);
        if( rawVoltageLastValue != rawVoltage ) {
          Serial.printf("rawVoltage:     %d\n", rawVoltage);
          rawVoltageLastValue = rawVoltage;
        }
        Serial.printf("without corr.: %1.1f busvoltage: %1.1f\n", ((((float)rawVoltage * ADC_MAX_VOLTAGE) / ADC_RESOLUTION) * U_DEVIDER), ((((float)rawVoltage * ADC_MAX_VOLTAGE) / ADC_RESOLUTION) * U_DEVIDER) + adcCorrection);
      #else
        if( max_init ) {
          Serial.printf("Voltage = %f\n", fuelGauge.getVoltage());
          Serial.printf("Battery Percentage %f\n", fuelGauge.getSOC());
        }
        else
          Serial.println("MAX1704x init failed, no info about anything");
      #endif
    #endif
  }
}   
